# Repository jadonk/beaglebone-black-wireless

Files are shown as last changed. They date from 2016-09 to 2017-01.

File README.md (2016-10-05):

# BeagleBoard.org BeagleBone Black Wireless
WiFi/BT version of BeagleBone Black done in EAGLE

# Terms
These design materials are *NOT SUPPORTED* and *DO NOT* constitute a reference design. Only “community” support is allowed via resources at [BeagleBoard.org/discuss](https://beagleboard.org/discuss).

THERE IS NO WARRANTY FOR THE DESIGN MATERIALS, TO THE EXTENT PERMITTED BY APPLICABLE LAW. EXCEPT WHEN OTHERWISE STATED IN WRITING THE COPYRIGHT HOLDERS AND/OR OTHER PARTIES PROVIDE THE DESIGN MATERIALS “AS IS” WITHOUT WARRANTY OF ANY KIND, EITHER EXPRESSED OR IMPLIED, INCLUDING, BUT NOT LIMITED TO, THE IMPLIED WARRANTIES OF MERCHANTABILITY AND FITNESS FOR A PARTICULAR PURPOSE. THE ENTIRE RISK AS TO THE QUALITY AND PERFORMANCE OF THE DESIGN MATERIALS IS WITH YOU. SHOULD THE DESIGN MATERIALS PROVE DEFECTIVE, YOU ASSUME THE COST OF ALL NECESSARY SERVICING, REPAIR OR CORRECTION.

We mean it, these design materials may be totally unsuitable for any purposes.

Do not use the BeagleBoard.org logo on your products without a [logo license](https://beagleboard.org/logo), but feel free to reference BeagleBoard.org.

See the [LICENSE](https://github.com/beagleboard/beaglebone-black-wireless/blob/master/LICENSE) file regarding the copyright of these materials.

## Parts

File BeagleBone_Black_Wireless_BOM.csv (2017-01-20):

Parts | Qty | Manufacturer | MPN | Description
BAG | 1 |  | 50-18 | 3x5 Open Top Anti-Static Bag
 |  | Desco | 13605
BOX | 1 |  |  | BeagleBone Black Wireless Box
CABLE | 1 |  | 13564 | USB 2.0 A to Micro B Cable 3ft
 |  | Molex | 68784-0002
PCB | 1 |  | BeagleBone Black Wireless A5b | BeagleBone Black Wireless A5b
QSG | 1 |  |  | BeagleBone Black Wireless Quick Start
ANT1-1, ANT2-1 | 2 | Anaren Microwave | 66089-2430 | 2.4GHz Whip, Straight RF Antenna 3dBi Connector, U.FL Connector Mount
ANT1, ANT2 | 2 | Hirose | U.FL-R-SMT-1(10) | CONN UMC JACK STR 50 OHM SMD
BT, PWR, USR0. USR1, USR2, USR3, WL | 7 | Lite-On | LTST-C191TBKT | LED BLUE CLEAR THIN 0603 SMD
C1, C19, C20, C61 | 4 | Samsung | CL10A106MQ8NNNC | CAP. 10uF 6.3V (0603)
C16, C55, C56 | 3 | Samsung | CL10A225KQ8NNNC | CAP. 2.2uF 6.3V (0603)
C2, C13, C15, C17, C18, C21, C22, C24, C25, C43. C44, C45, C47, C48, C49, C50, C51, C52, C53, C58, C59, C63, C69 | 23 | Murata | GRM155R60J104KA01D | CAP CER 0.1UF 6.3V 10% X5R 0402
C27, C28, C29, C30, C31, C32, C33, C34, C35, C36, C37, C39, C40, C41, C42 | 16 | Yageo | CC0402JRNPO9BN470 | CAP CER 47PF 50V 5% NPO 0402
C3, C4, C5, C6 | 4 | NIC Components | NMC0402NPO180J50TRPF | CAP CER 18PF 50V C0G 5% 0402
C46, C60 | 2 | Samsung | CL05C100JB5NNNC | CAP. 10pF 50V (0402)
C62 | 1 | AVX | TAJD227M010RNJ | CAP. 220uF TANT. 10V (7343)
 |  | AVX | TAJD227K010RNJ
C7 | 1 | Samsung | CL21A475KOFNNNE | CAP. 4.7uF (0805)
C8, C10, C64 | 3 | Murata | GRM155R60J105KE19D | CAP CER 1UF 6.3V 10% X5R 0402
C9, C12, C14, C54, C57 | 5 | Samsung | CL21B225KOFNNNE | CAP. 2.2uF 16V (0805)
D1 | 1 | NXP Semiconductors | RB751V40,115 | DIODE SCHOTTKY 40V 120MA SOD-323
D3. D4 | 2 | Diodes Inc. | B130L-13-F | B130L-13 (SMA)
D8 | 1 | ON Semiconductor | BAT54CLT1G | BAT54C (SOT-23)
F1 | 1 | Littelfuse | 1206L050YR | 1206L050YR (1206)
FB1 | 1 | Murata | BLM21AG221SN1D | FB 220 OHM 0805
FB2 | 1 | Murata | BLM18BD252SN1D | FB 2.5K (0603)
FB3 | 1 | Laird | LI0805H151R-10 | Ferrite Bead 150 Ohm 800mA
FB4, R17 | 2 | CTS Components | 73L3R10J | RES .10 OHM 1/8W 5% 0805
FB5, FB6, FB7 | 3 | Murata | BLM15AG102SN1D | FERRITE BEAD 1 KOHM 0402 1LN
IC1 | 1 | Octavo Systems | OSD3358-512M-BAS | OSD3358-512M-BAS-XB for Beagleboard.org
IC10, IC11 | 2 | Texas Instruments | TXS0108ERGYR | IC XLATR VOLT-LVL 8B BDIR 20QFN
IC12 | 1 | Texas Instruments | TPS2051BDGNR | IC 1.5A PWR DIST SWITCH 8-SOIC
IC13 | 1 | Texas Instruments | SN74AUC1G74DCTR | IC D-TYPE POS TRG SNGL SM8
IC14, IC15 | 2 | Texas Instruments | TPD4S012DRYR | IC 4CH ESD SOLUTION W/CLAMP 6SON
IC17 | 1 | Texas Instruments | SN74LVC2G241DCUR | IC BUFF/DVR TRI-ST DL 8VSSOP
IC18 | 1 | Texas Instruments | TL1963ADCQR | IC REG LDO ADJ 1.5A SOT223-6
IC19 | 1 | Diodes Inc. | AP2112K-1.8TRG1 | AP2112K-1.8TRG1
IC2 | 1 | Texas Instruments | SN74LVC1G07DCKR | IC BUFF/DVR NON-INVERT SC705
IC22 | 1 | Kingston | EMMC04G-S100-B08U | IC MEMORY, 4GB eMMC
IC3 | 1 | Texas Instruments | SN74LVC1G06DCKR | IC INVERTER SINGLE 1INPUT SC705
IC4 | 1 | Microchip | 24LC32AT-I/OT | IC EEPROM 32KBIT 400KHZ SOT23-5
IC5 | 1 | Texas Instruments | TLVH431IDBZR | IC VREF SHUNT ADJ SOT23-3
IC7, IC8 | 2 | NXP Semiconductors | IP4283CZ10-TBR | TVS DIODE 5.5VWM 9.5VC 10DFN
IC9 | 1 | NXP Semiconductors | TDA19988BHN/C1,557 | IC HDMI INTERFACE HVQFN64
MOD1 | 1 | Texas Instruments | WL1835MODGBMOCR | MODULE WIFI WILINK
OSC1 | 1 | Abracon | ASDMB-24.576MHZ-LC-T | Oscillator, 24.576MHZ, 3.3V
OSC2 | 1 | NDK | NZ2520SB-32.768KHZ-NSA3534C | OSC XO 32.768KHZ CMOS SMD
P8, P9 | 2 | Major League Electronics | SSHS-123-D-02-GT-LF | NN HEADER FMAL 46PS.1" DL GOLD"
POWER, RESET, S2 | 3 | C&K Components | KMR231GLFS | Mini Switch
 |  | Zhejiang Jianfu Electronics Co., LTD. | TVAF02-NB-R
Q2 | 1 |  | 6K30032768K0702070401 | 3.2x1.5 2pads 32.768kHz 7pF 20ppm
 |  | Interquip | 9CAA32768072TF70QT
Q4 | 1 | TXC | 7A-24.000MAAJ-T | CRYSTAL 24.000 MHZ 18PF SMD
R1, R2, R3, R4, R5, R6, R7, R12, R13, R16, R18, R19, R20, R23, R24, R25, R28, R30, R31, R32, R33, R40, R46, R98, R99, R101, R102, R103, R105, R119, R121 | 31 | Samsung | RC1005F103CS | RES. 10K 1% (0402)
R10, R11 | 2 | Samsung | RC1005J154CS | RES. 150K 5% (0402)
R120 | 1 | Yageo | RC0402FR-0727KL | RES 27K OHM 1/16W 1% 0402 SMD
R14, R26, R27, R29, R35, R36, R37, R38, R39, R54, R114, R122 | 12 | Yageo | RC0402JR-070RL | Resistor Zero ohm Jumper 0402
R21, R22, R43, R52, R53, R55 | 6 | NIC Components | NRC04F4751TRF | RES 4.75K OHM 1/16W 1% 0402 SMD
R34 | 1 | NIC Components | NRC04J220TRF | Resistor 22ohm 1/16W 1% 0402
R41, R42, R106, R115, R118 | 5 | Yageo | RC0402FR-071K5L | RES 1.50K OHM 1/16W 1% 0402 SMD
 |  |  | RC0402FR-071ML
R44 | 1 | Samsung | RC1005F4990CS | RES. 499 OHM 1% (0402)
R47 | 1 | Samsung | RC1005F4022CS | RES. 40.2K 1% (0402)
R57, R58, R61, R63, R65, R67, R69, R71, R73, R75, R76, R78, R80, R82, R85, R87, R123 | 17 | Yageo | RC0402FR-07100KL | Resistor 100Kohm 1/16W 1% 0402
R60, R62, R64, R66, R68, R70, R72, R110, R140, R141, R142, R143 | 12 | Yageo | RC0402JR-0733RL | RES 33 OHM 1/16W 5% 0402 SMD
R8, R95 | 2 | Yageo | RC0402FR-071ML | Resistor 1Mohm 1/16W 1% 0402
R86, R126, R127, R128, R129, R130, R131, R134, R135, R136 | 10 | Samsung | RC1608J330CS | RES. 33 OHM 5% (0603)
R88 | 1 | Samsung | RC1005F101CS | RES. 100 OHM 1% (0402)
R89, R90, R92, R96, R100, R104, R124, R125 | 8 | Samsung | RC1005J102CS | RES. 1K 5% (0402)
R93 | 1 | Samsung | RC1005F7151CS | RES. 7.15K 1% (0402)
R94 | 1 | Samsung | RC1005F4121CS | RES 4.12K OHM 1/16W 1% 0402 SMD
T1 | 1 | ON Semiconductor | MMBT2907ALT1G | TRANS PNP 60V 0.6A SOT23
T3, T4 | 2 | Diodes Inc. | BSS138W-7-F | MOSFET N-CH 50V 200MA SC70-3
X1 | 1 | FCI | 68000-406HLF | CONN HEADER 6POS, VERTICAL, .100 STR TIN
X12 | 1 | CUI | PJ-102A | Power Jack
X2 | 1 | ALPS | SCHA5B0200 | Connector SD/MMC
X3 | 1 | TE Connectivity / AMP | 787616-1-P | Single Row USB Right Angle
 |  |  | LY-USB-004-001-A1
X4 | 1 | FCI | 10118192-0001LF | USB - micro B USB 2.0 Receptacle Connector 5 Position Surface Mount, Right Angle, Horizontal
X5 | 1 | FCI | 10118241-001RLF | HDMI / Displayport / DVI Connectors MICRO HDMI RCPT SMT DIP+ SMT LEG TYPE D

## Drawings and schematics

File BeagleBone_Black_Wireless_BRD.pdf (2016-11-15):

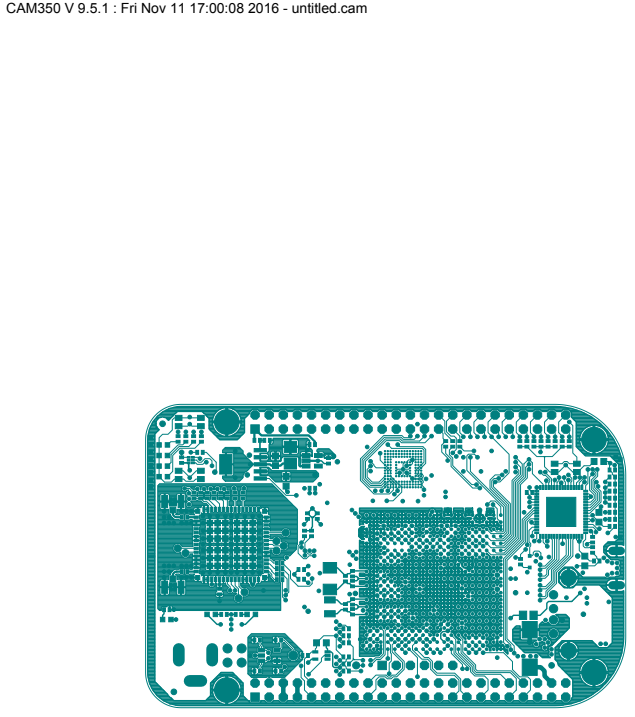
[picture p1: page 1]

CAM350 V 9.5.1 : Fri Nov 11 17:00:08 2016 - untitled.cam

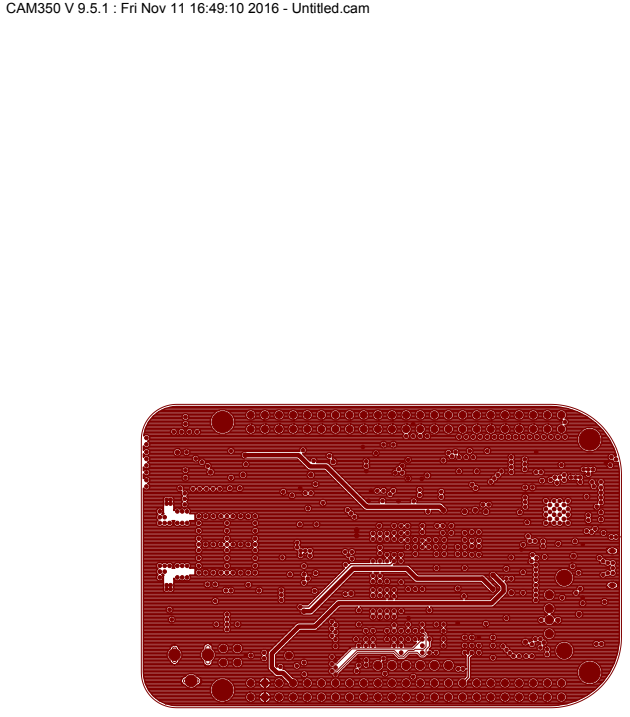
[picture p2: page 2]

CAM350 V 9.5.1 : Fri Nov 11 16:49:10 2016 - Untitled.cam

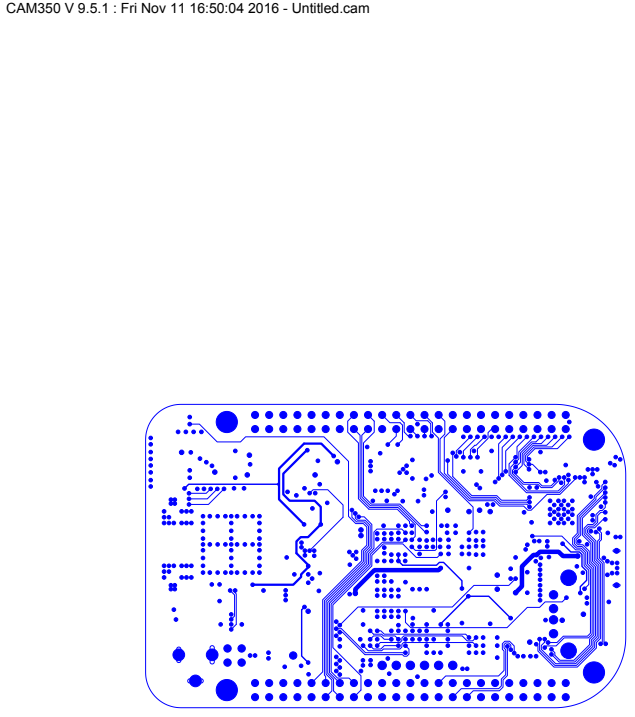
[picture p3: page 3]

CAM350 V 9.5.1 : Fri Nov 11 16:50:04 2016 - Untitled.cam

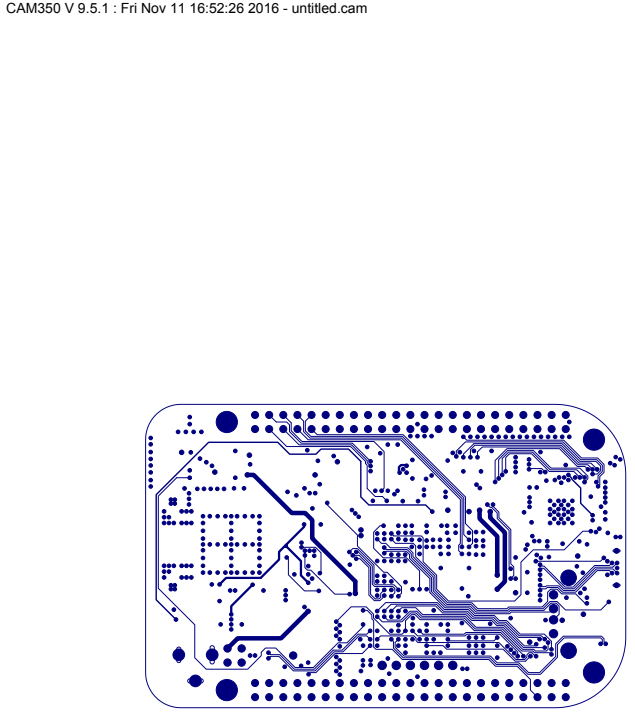
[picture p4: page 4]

CAM350 V 9.5.1 : Fri Nov 11 16:52:26 2016 - untitled.cam

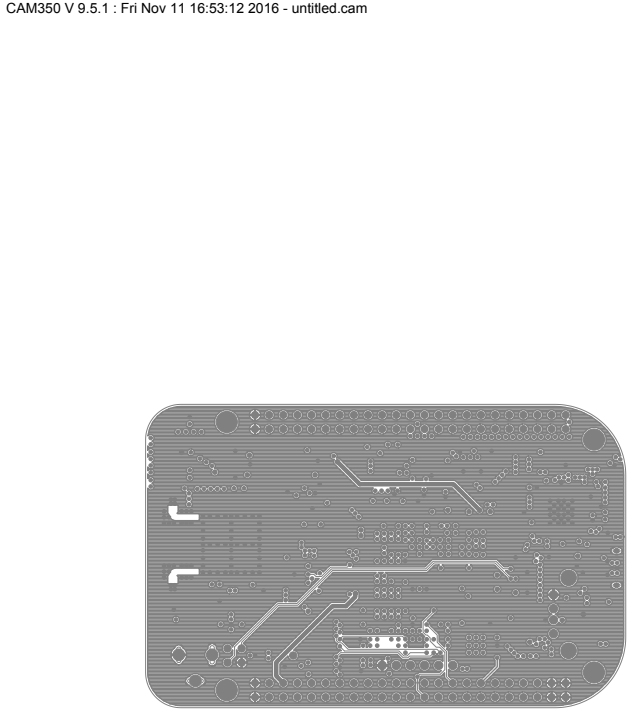
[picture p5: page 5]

CAM350 V 9.5.1 : Fri Nov 11 16:53:12 2016 - untitled.cam

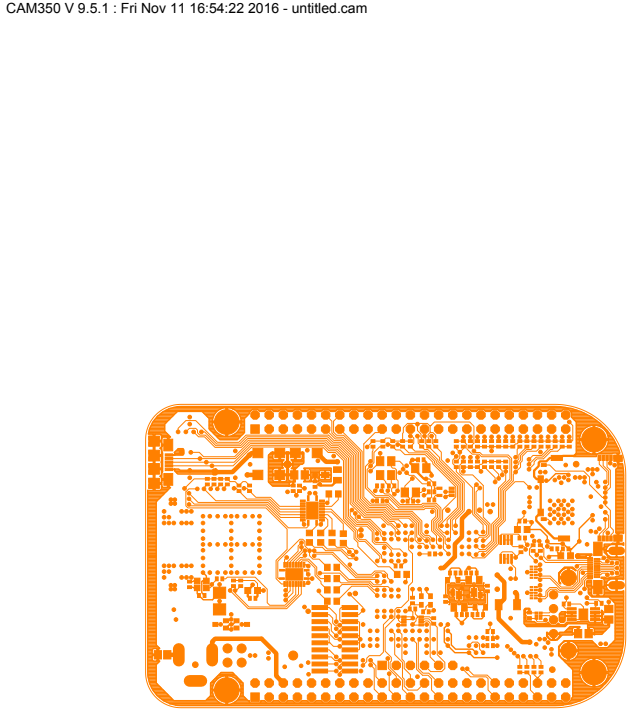
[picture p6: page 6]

CAM350 V 9.5.1 : Fri Nov 11 16:54:22 2016 - untitled.cam

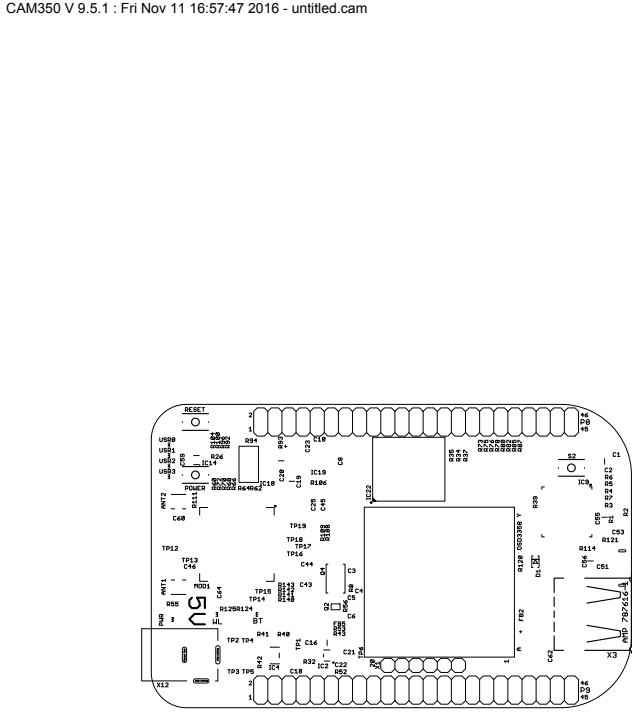
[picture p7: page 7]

CAM350 V 9.5.1 : Fri Nov 11 16:57:47 2016 - untitled.cam

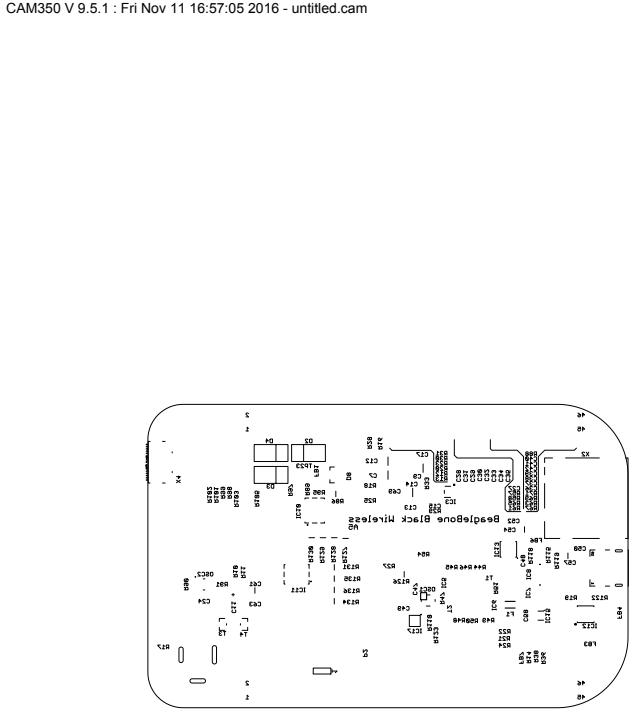
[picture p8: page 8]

CAM350 V 9.5.1 : Fri Nov 11 16:57:05 2016 - untitled.cam

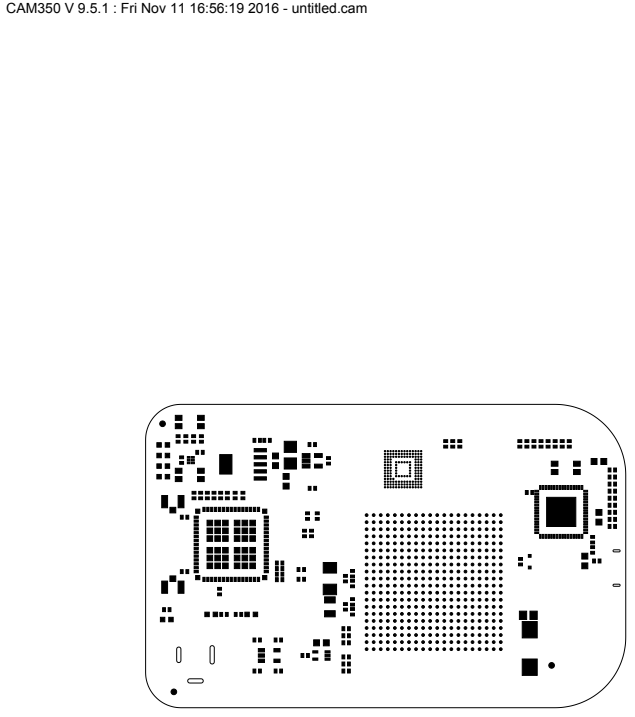
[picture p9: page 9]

CAM350 V 9.5.1 : Fri Nov 11 16:56:19 2016 - untitled.cam

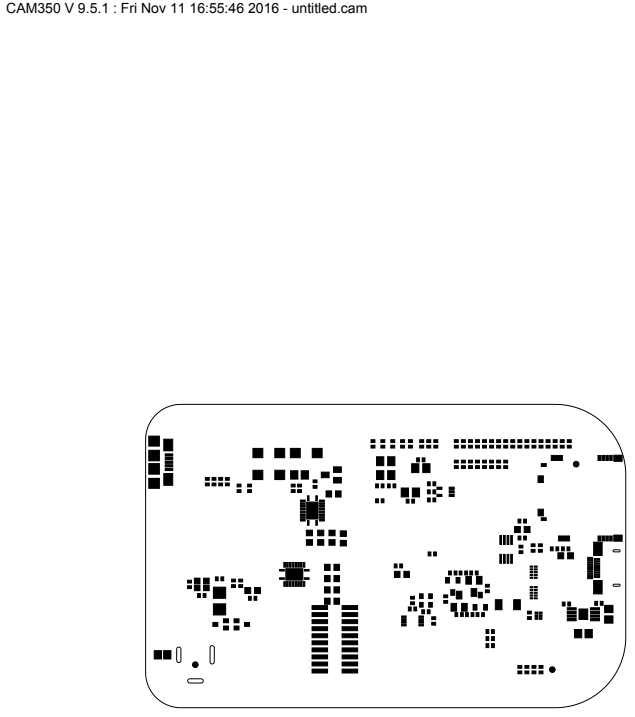
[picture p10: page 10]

CAM350 V 9.5.1 : Fri Nov 11 16:55:46 2016 - untitled.cam

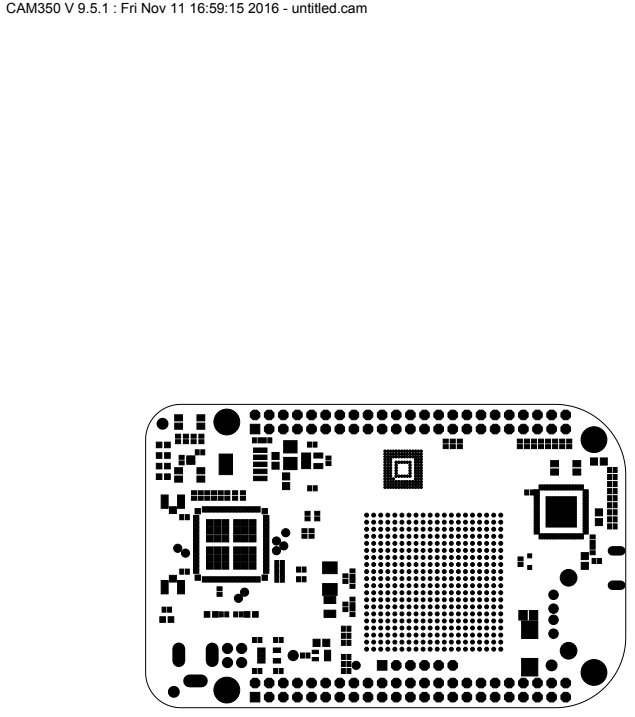
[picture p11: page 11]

CAM350 V 9.5.1 : Fri Nov 11 16:59:15 2016 - untitled.cam

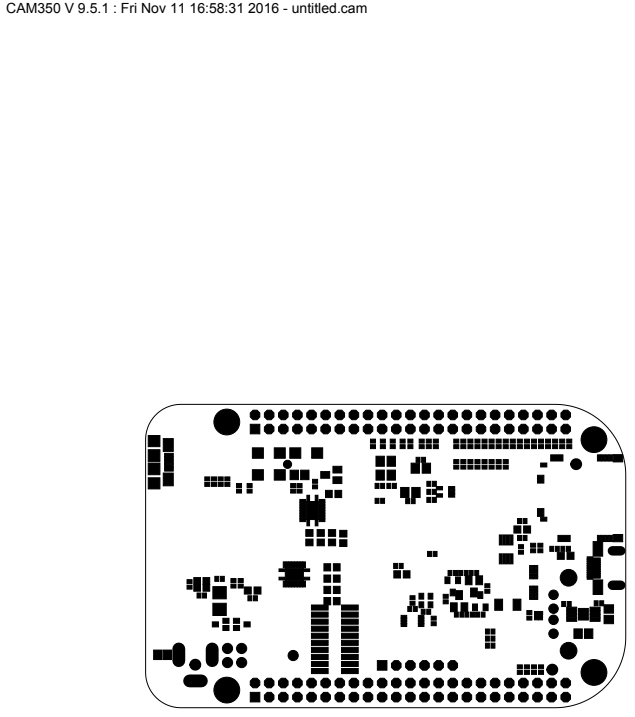
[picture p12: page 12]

CAM350 V 9.5.1 : Fri Nov 11 16:58:31 2016 - untitled.cam


CAM350 V 9.5.1 : Fri Nov 11 16:55:00 2016 - untitled.cam


CAM350 V 9.5.1 : Fri Nov 11 17:02:55 2016 - untitled.cam


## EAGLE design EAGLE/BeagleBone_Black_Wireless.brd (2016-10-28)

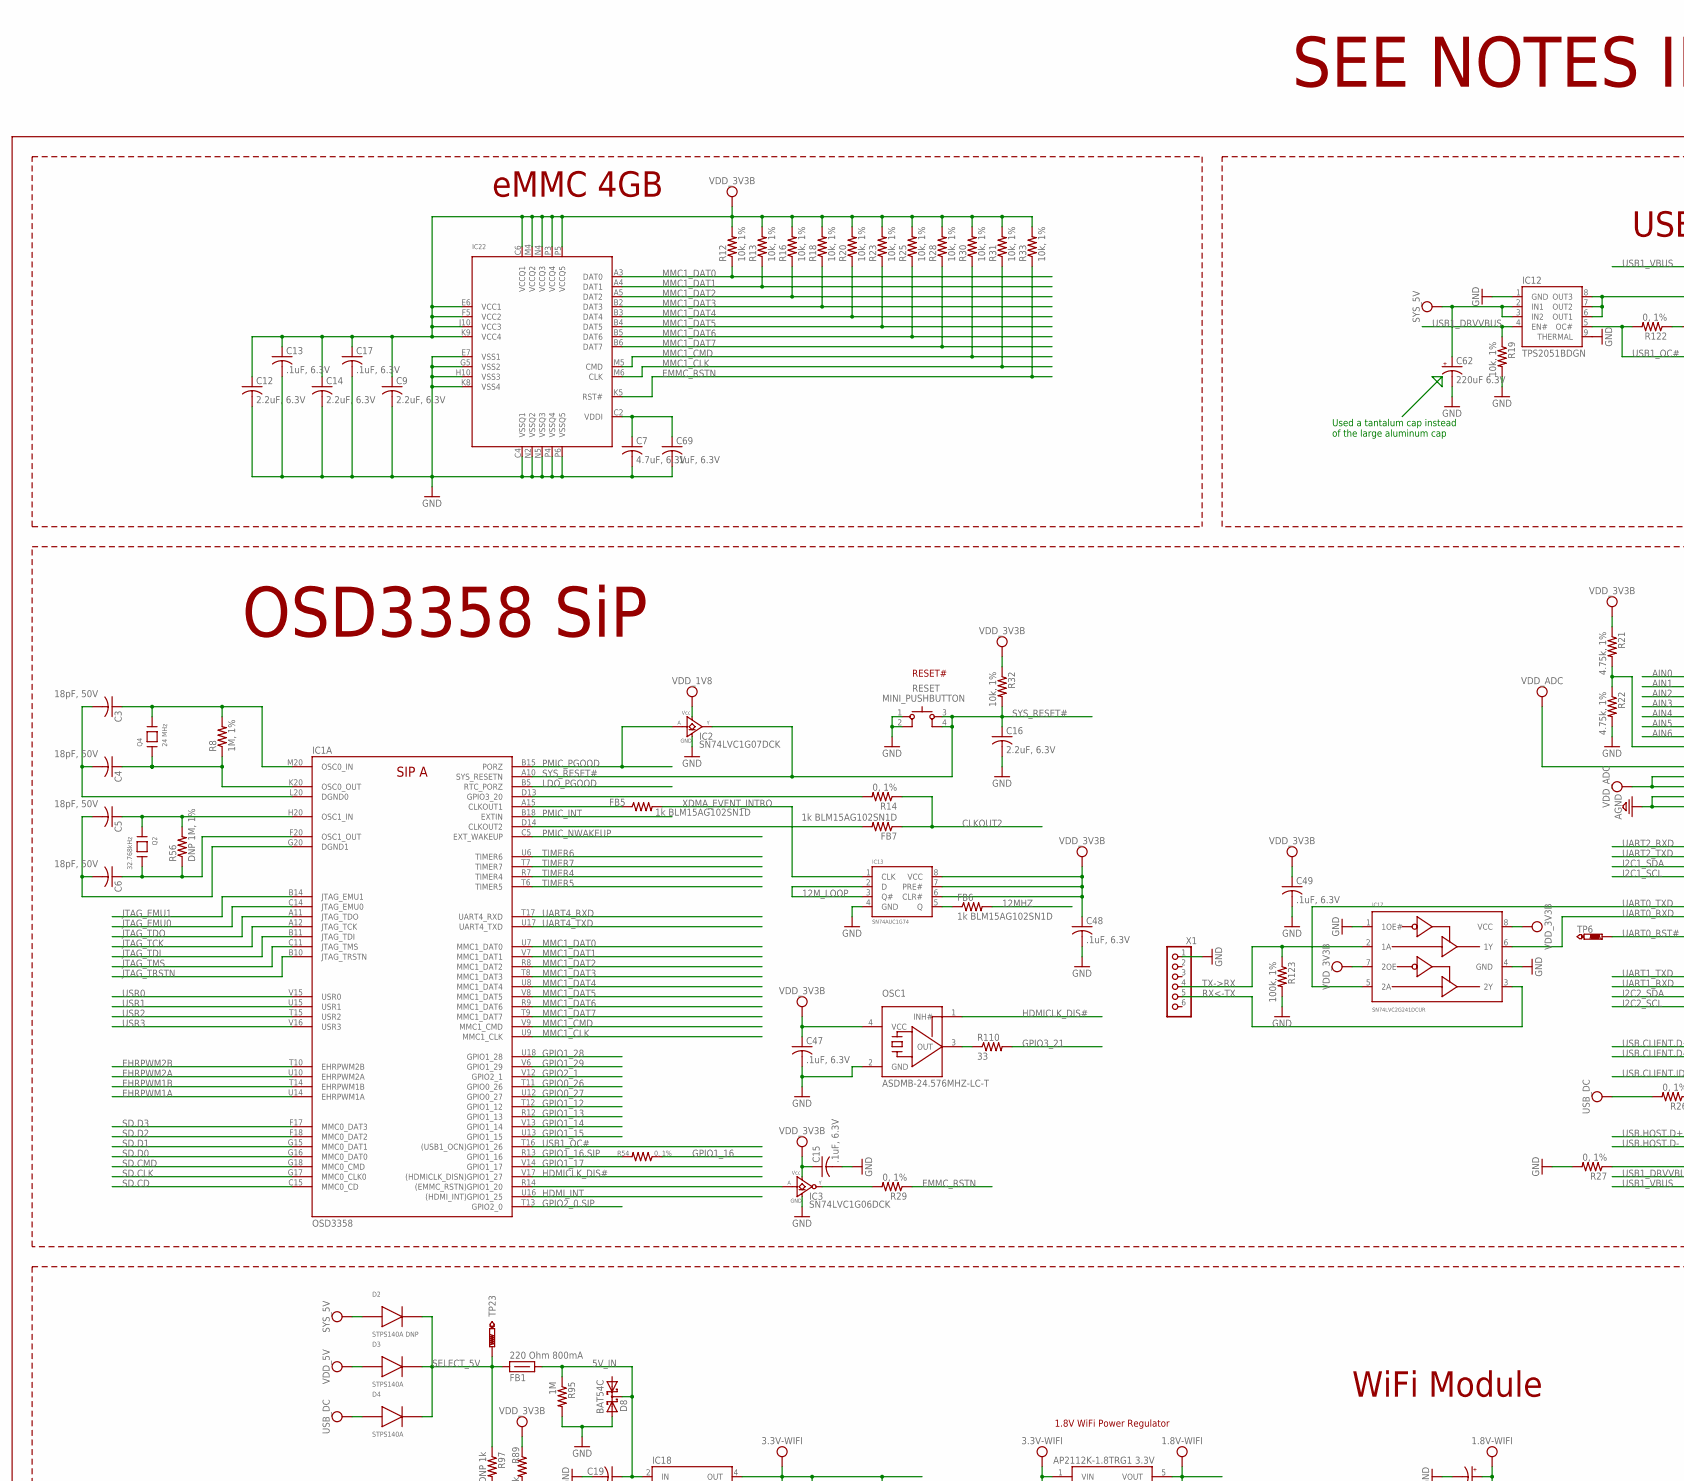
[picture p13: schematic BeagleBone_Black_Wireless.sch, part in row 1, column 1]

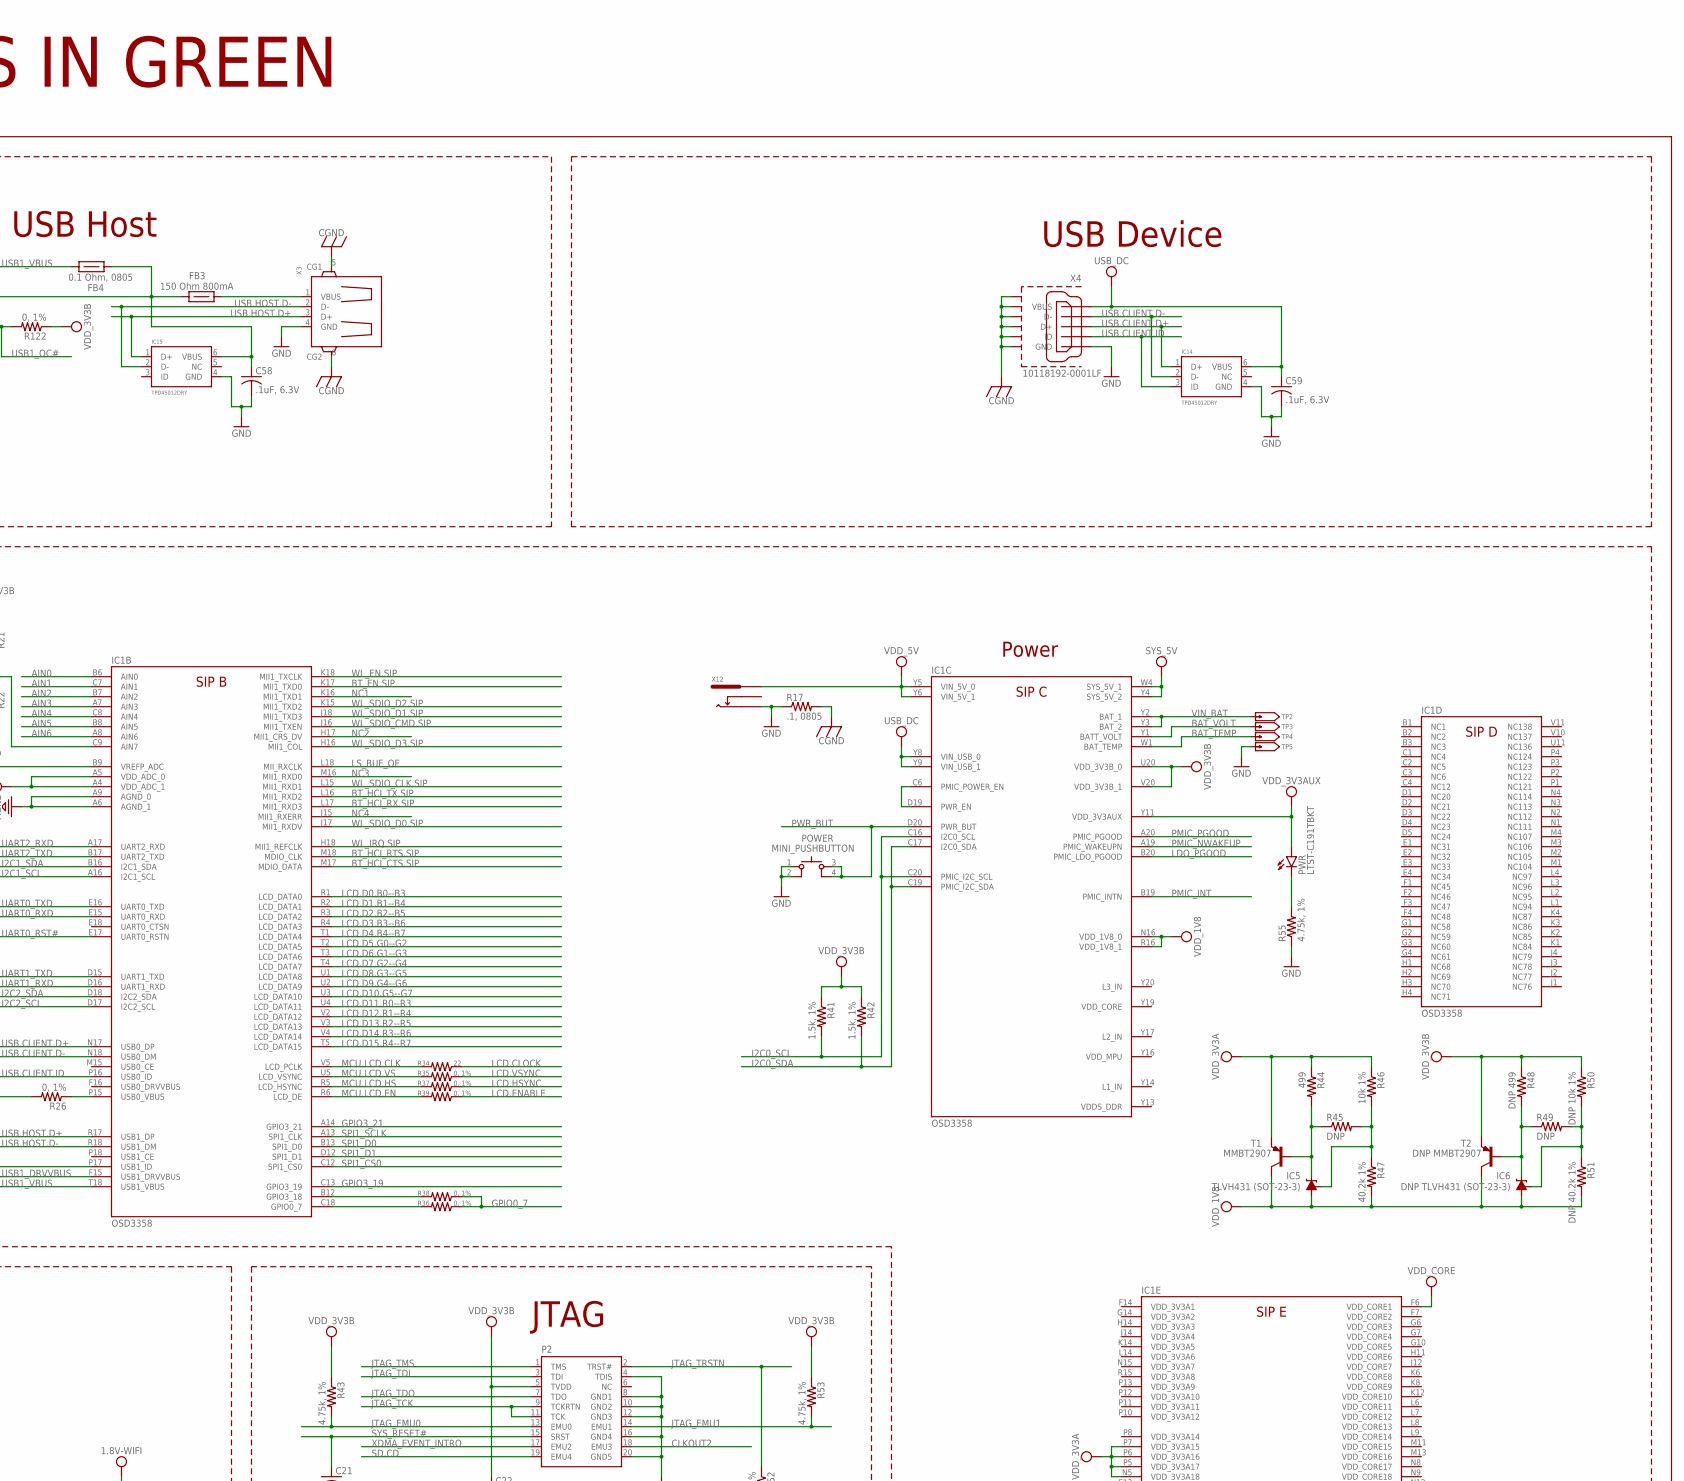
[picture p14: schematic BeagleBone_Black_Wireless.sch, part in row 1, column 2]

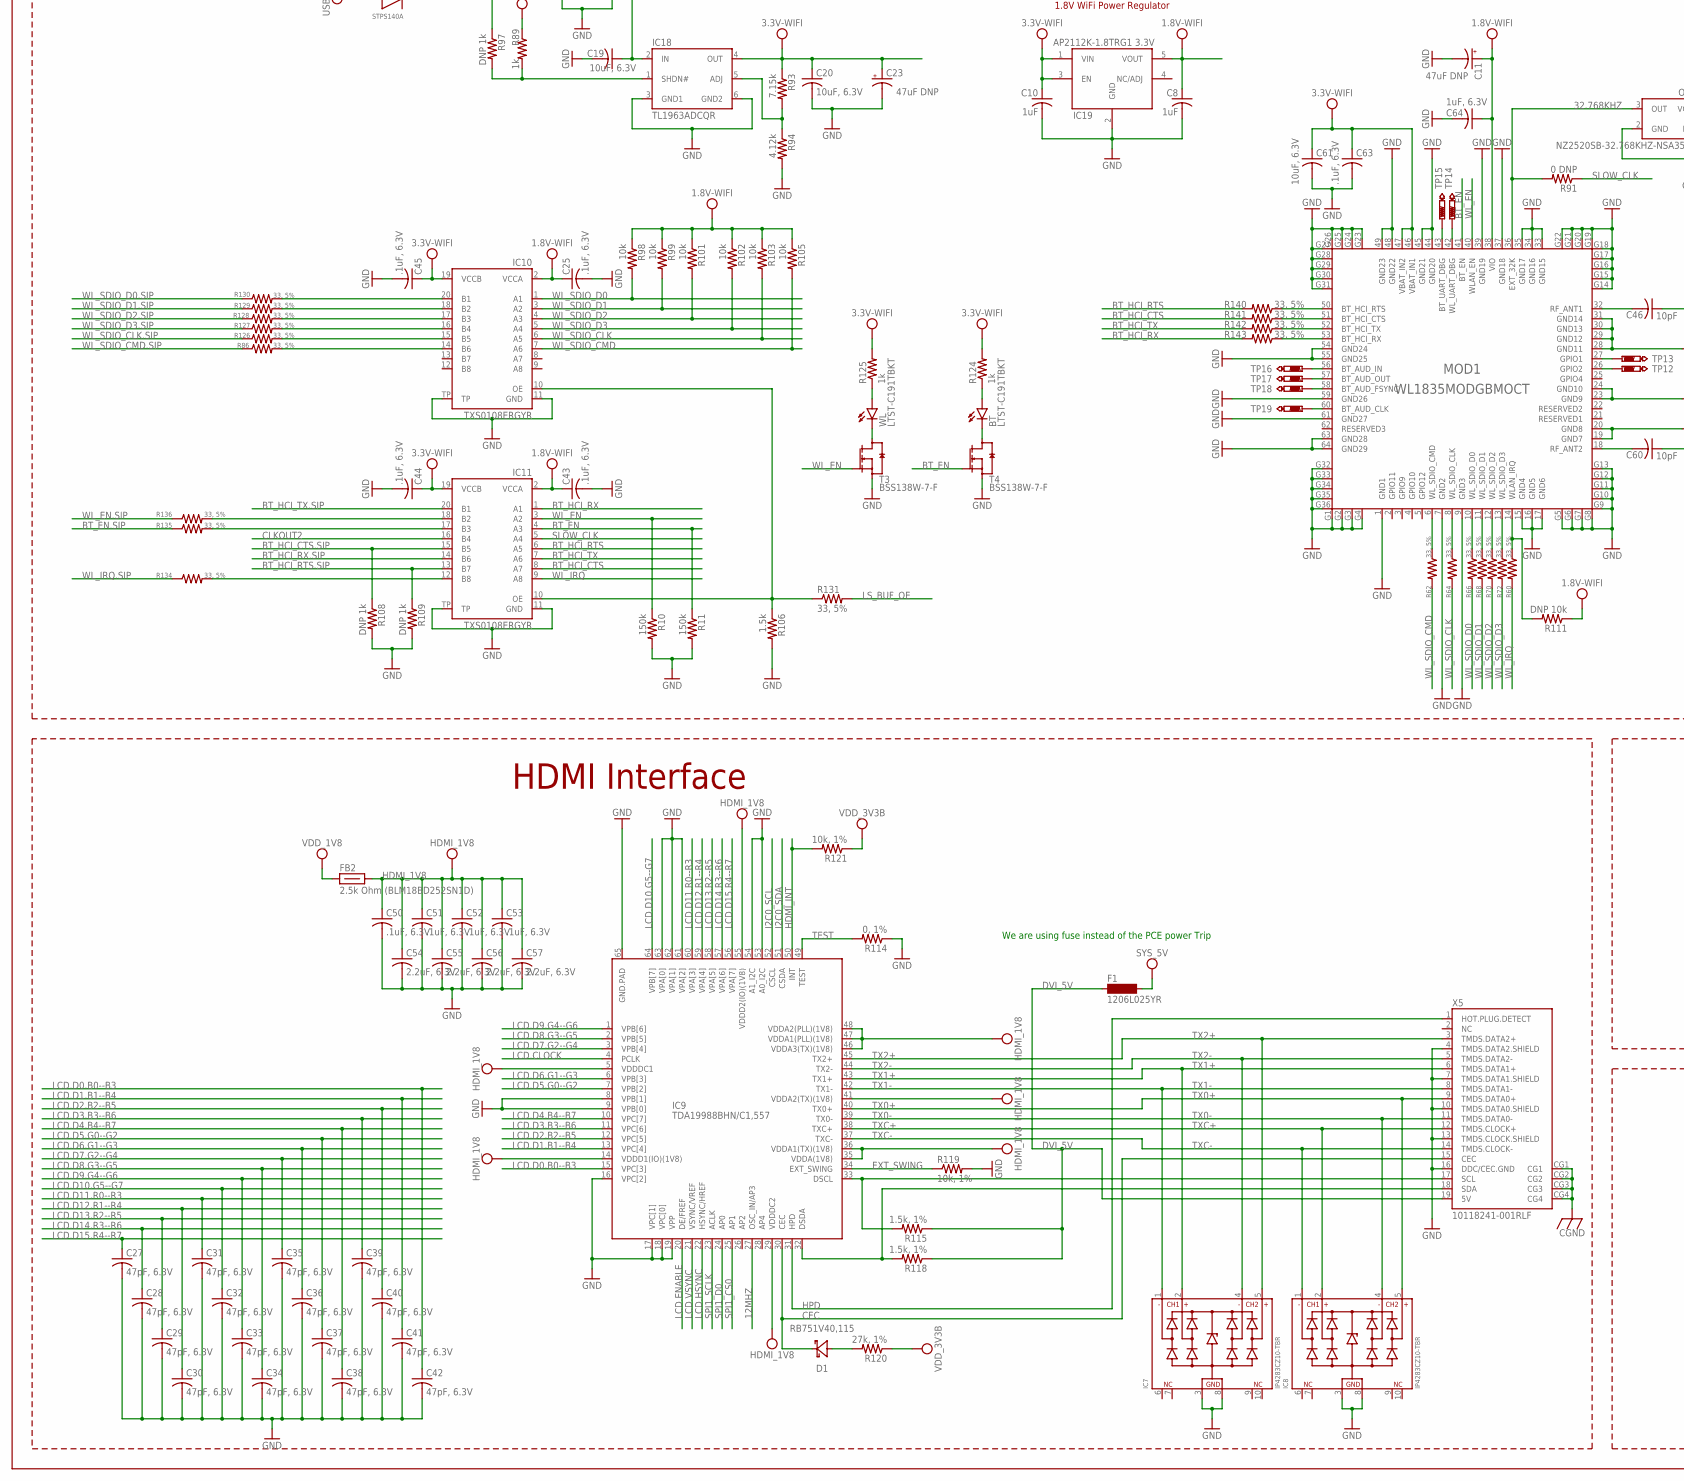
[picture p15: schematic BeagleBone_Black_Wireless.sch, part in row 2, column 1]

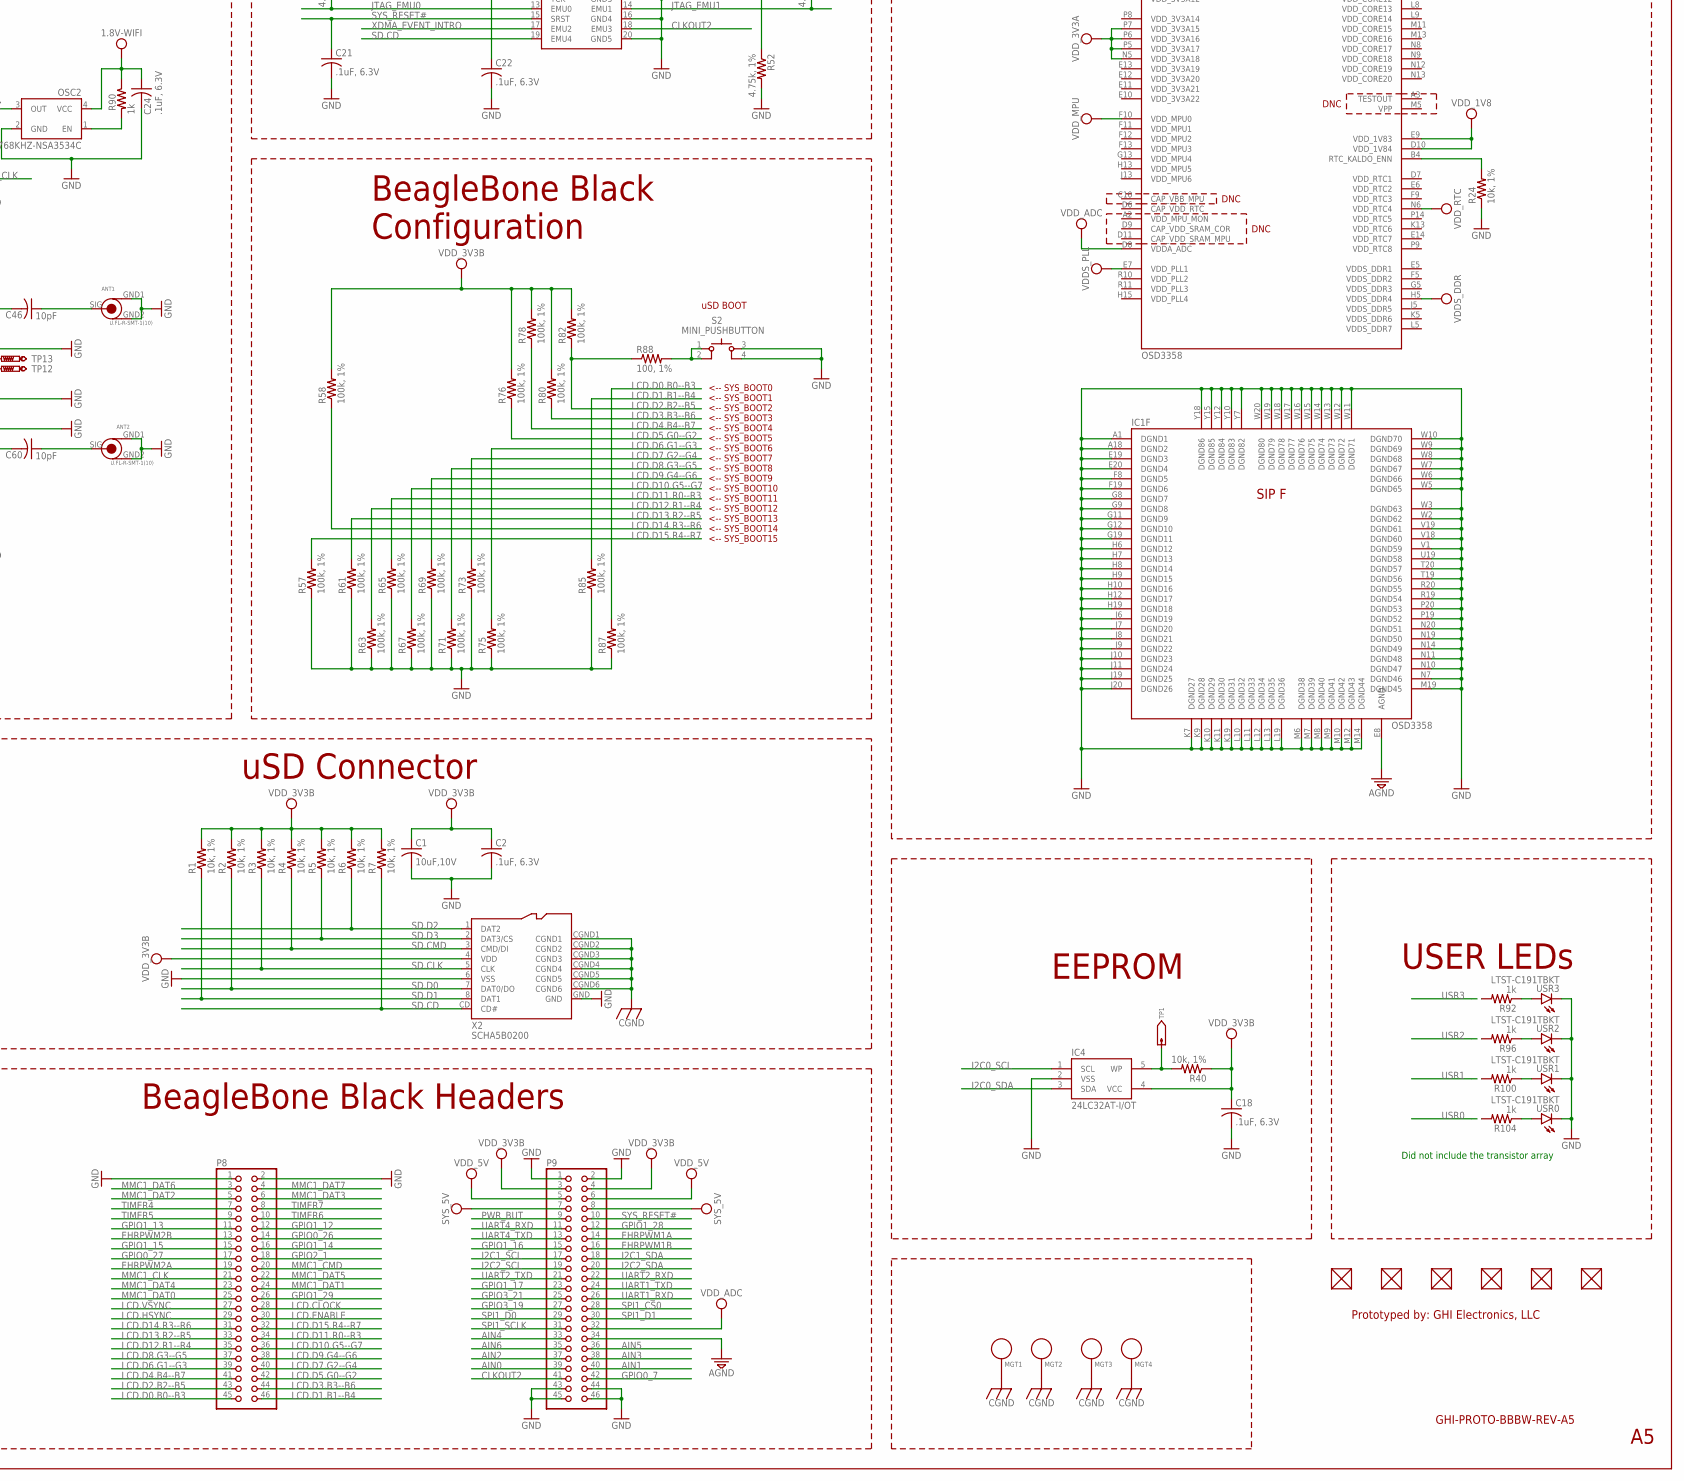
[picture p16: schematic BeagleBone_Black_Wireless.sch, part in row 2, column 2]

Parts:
ANT1, ANT2: U.FL-R-SMT-1(10); U.FL-R-SMT-1
BT: LTST-C191TBKT; 0603-LED
C1: 10uF,10V; C0603K
C2, C13, C15, C17, C18, C21, C22, C24, C25, C43, C44, C45, C47, C48, C49, C50, C51, C52, C53, C58, C59, C63, C69: .1uF, 6.3V; C0402K
C3, C4, C5, C6: 18pF, 50V; C0402K
C7: 4.7uF, 6.3V; C0805K
C8, C10: 1uF; C0402K
C9, C12, C14: 2.2uF, 6.3V; C0805K
C11, C23: 47uF DNP; CT3528
C16, C54, C55, C56, C57: 2.2uF, 6.3V; C0603K
C19, C20, C61: 10uF, 6.3V; C0603K
C27, C28, C29, C30, C31, C32, C33, C34, C35, C36, C37, C38, C39, C40, C41, C42: 47pF, 6.3V; C0402K
C46, C60: 10pF; C0402K
C62: 220uF 6.3V; D/7343-31W
C64: 1uF, 6.3V; C0402K
D1: RB751V40,115; SOD323(NXP)REFLOW
D2: STPS140A DNP; DIODE_SMA
D3, D4: STPS140A; DIODE_SMA
D8: BAT54C; SOT23
F1: 1206L025YR; SM-1206
FB1: 220 Ohm 800mA; 0805-RESISTOR
FB2: 2.5k Ohm (BLM18BD252SN1D); 0805-RESISTOR
FB3: 150 Ohm 800mA; 0805-RESISTOR
FB4: 0.1 Ohm, 0805; 0805-RESISTOR
FB5, FB6, FB7: 1k BLM15AG102SN1D; R0402
FUD1, FUD2, FUD3, FUD4, FUD5, FUD6: FIDUCIAL; FIDUCIAL_40MIL
IC1: OSD3358
IC2: SN74LVC1G07DCK; SC70(TI-DCK)
IC3: SN74LVC1G06DCK; SC70(TI-DCK)
IC4: 24LC32AT-I/OT; SOT23-5(MICROCHIP)
IC5: TLVH431 (SOT-23-3); DBZ_R-PDSO-G3
IC6: DNP TLVH431 (SOT-23-3); DBZ_R-PDSO-G3
IC7, IC8: IP4283CZ10-TBR; SOT1176-1(NXP)
IC9: TDA19988BHN/C1,557; SOT804-4(NXP)
IC10, IC11: TXS0108ERGYR; R-PVQFN-N20(TI)
IC12: TPS2051BDGN; MSOP-POWER.PAD-8(TI)
IC13: SN74AUC1G74; SM8-8(TI)
IC14, IC15: TPD4S012DRY; SON-6(TI)-DRY
IC17: SN74LVC2G241DCUR; VSSOP8(TI)
IC18: TL1963ADCQR; SOT-223(DCQ_R-PDSO-G6_TI)
IC19: AP2112K-1.8TRG1 3.3V; SOT23-5
IC22: EMMC04G-S100-B08U; MICRON_EMMC_153
MGT1, MGT2, MGT3, MGT4: MOUNTING_HOLE
MOD1: WL1835MODGBMOCT; MOC-100(TI)
OSC1: ASDMB-24.576MHZ-LC-T; OSCILLATOR-2.5X2.0-BBB
OSC2: NZ2520SB-32.768KHZ-NSA3534C; NZ2520S
P2: JTAG
P8, P9: HEADER-2X23-(INCH)-0.1-TH; TH-2X23
POWER: MINI_PUSHBUTTON
PWR: LTST-C191TBKT; 0603-LED
Q2: 32.768kHz; CRYSTAL_3.2X1.5
Q4: 24 MHz; CRYSTAL_5X3.2MM
R1, R2, R3, R4, R5, R6, R7, R12, R13, R16, R18, R19, R20, R23, R24, R25, R28, R30, R31, R32, R33, R40, R119, R121: 10k, 1%; R0402
R8: 1M, 1%; R0402
R10, R11: 150k; R0402
R14, R26, R27, R29, R35, R36, R37, R38, R39, R54, R114, R122: 0, 1%; R0402
R17: .1, 0805; R0805
R21, R22, R43, R52, R53, R55: 4.75k, 1%; R0402
R34: 22; R0402
R41, R42, R115, R118: 1.5k, 1%; R0402
R44: 499; R0402
R45, R49: DNP; R0402
R46: 10k 1%; R0402
R47: 40.2k 1%; R0402
R48: DNP 499; R0402
R50: DNP 10k 1%; R0402
R51: DNP 40.2k 1%; R0402
R56: DNP 1M, 1%; R0402
R57, R58, R61, R63, R65, R67, R69, R71, R73, R75, R76, R78, R80, R82, R85, R87, R123: 100k, 1%; R0402
R60, R62, R64, R66, R68, R70, R72, R140, R141, R142, R143: 33, 5%; R0402
R86, R126, R127, R128, R129, R130, R131, R134, R135, R136: 33, 5%; R0603
R88: 100, 1%; R0402
R89, R90, R92, R96, R100, R104, R124, R125: 1k; R0402
R91: 0 DNP; R0402
R93: 7.15k; R0402
R94: 4.12k; R0402
R95: 1M; R0402
R97, R108, R109: DNP 1k; R0402
R98, R99, R101, R102, R103, R105: 10k; R0402
R106: 1.5k; R0402
R110: 33; R0402
R111: DNP 10k; R0402
R120: 27k, 1%; R0402
RESET: MINI_PUSHBUTTON
S2: MINI_PUSHBUTTON
T1: MMBT2907; SOT23-BEC
T2: DNP MMBT2907; SOT23-BEC
T3, T4: BSS138W-7-F; SOT-323(DIODES)
TP1, TP2, TP3, TP4, TP5: TESTPAD/W_HOLE_1X1
TP6, TP12, TP13, TP14, TP15, TP16, TP17, TP18, TP19, TP23: PTR1B1,27; B1,27
USR0, USR1, USR2, USR3: LTST-C191TBKT; 0603-LED
WL: LTST-C191TBKT; 0603-LED
X1: 1X6-(INCH)-0.1-TH; TH-1X6
X2: SCHA5B0200
X3: USB_HOST_W/CHASSIS_GND; USB_HOST_HORIZONTAL_W/CHASSIS_GND
X4: 10118192-0001LF; 10118192-0001LF(MICRO-USB-B-AMPHENOL-FCI)
X5: 10118241-001RLF; HDMI-TYPE-D-10118241
X12: PJ-102B_POWER_CON

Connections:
1.8V-WIFI: C8.1, C11.+, C24.1, C25.1, C43.1, C64.1, IC10.2 (VCCA), IC11.2 (VCCA), IC19.5 (VOUT), MOD1.38 (VIO), OSC2.4 (VCC), R90.1, R98.1, R99.1, R101.1, R102.1, R103.1, R105.1, R111.1
3.3V-WIFI: C10.1, C20.1, C23.+, C44.1, C45.1, C61.1, C63.1, IC10.19 (VCCB), IC11.19 (VCCB), IC18.4 (OUT), IC19.1 (VIN), IC19.3 (EN), MOD1.46 (VBAT_IN1), MOD1.47 (VBAT_IN2), R93.1, R124.2, R125.2
5V_IN: C19.1, D8.3 (CC), FB1.2, IC18.2 (IN), R95.1
12MHZ: FB6.2, IC9.27 (OSC_IN/AP3)
12M_LOOP: IC13.2 (D), IC13.3 (Q#)
32.768KHZ: MOD1.36 (EXT_32K), OSC2.3 (OUT), R91.2
AGND: IC1.A6 (AGND_1), IC1.A9 (AGND_0), IC1.E8 (AGND), P9.34
AIN0: IC1.B6 (AIN0), P9.39
AIN1: IC1.C7 (AIN1), P9.40
AIN2: IC1.B7 (AIN2), P9.37
AIN3: IC1.A7 (AIN3), P9.38
AIN4: IC1.C8 (AIN4), P9.33
AIN5: IC1.B8 (AIN5), P9.36
AIN6: IC1.A8 (AIN6), P9.35
AIN7: IC1.C9 (AIN7), R21.2, R22.1
ALT.BT.EN: IC11.17 (B3), R135.2
ALT.BUFF.OE: IC10.10 (OE), IC11.10 (OE), R106.1, R131.1
ALT.WL.CLK: IC10.15 (B5), R126.2
ALT.WL.CMD: IC10.14 (B6), R86.2
ALT.WL.D0: IC10.20 (B1), R130.2
ALT.WL.D1: IC10.18 (B2), R129.2
ALT.WL.D2: IC10.17 (B3), R128.2
ALT.WL.D3: IC10.16 (B4), R127.2
ALT.WL.EN: IC11.18 (B2), R136.2
ALT.WL.IRQ: IC11.12 (B8), R134.2
BAT_TEMP: IC1.W1 (BAT_TEMP), TP4.P$1
BAT_VOLT: IC1.Y1 (BATT_VOLT), TP3.P$1
BT_EN: IC11.4 (A3), MOD1.41 (BT_EN), R11.1, T4.G
BT_EN.SIP: IC1.K17 (MII1_TXD0), R135.1
BT_HCI_CTS: IC11.8 (A7), R141.2
BT_HCI_CTS.SIP: IC1.M17 (MDIO_DATA), IC11.15 (B5), R108.1
BT_HCI_RTS: IC11.6 (A5), R140.2
BT_HCI_RTS.SIP: IC1.M18 (MDIO_CLK), IC11.13 (B7), R109.1
BT_HCI_RX: IC11.1 (A1), R143.2
BT_HCI_RX.SIP: IC1.L17 (MII1_RXD3), IC11.14 (B6)
BT_HCI_TX: IC11.7 (A6), R142.2
BT_HCI_TX.SIP: IC1.L16 (MII1_RXD2), IC11.20 (B1)
CEC: D1.C (CATHODE), IC9.30 (CEC), X5.15 (CEC)
CGND: MGT1.P$1, MGT2.P$1, MGT3.P$1, MGT4.P$1, R17.2, X2.CGND1, X2.CGND2, X2.CGND3, X2.CGND4, X2.CGND5, X2.CGND6, X3.5 (CG1), X3.6 (CG2), X4.CGND1 (SGND1), X4.CGND2 (SGND2), X4.CGND3 (SGND3), X4.CGND4 (SGND4), X4.CGND5 (SGND5), X4.CGND6 (SGND6), X5.CG1, X5.CG2, X5.CG3, X5.CG4
CLKOUT2: FB7.1, IC11.16 (B4), P2.18 (EMU3), P9.41, R14.1
DVI_5V: F1.1, R115.1, R118.1, X5.19 (5V)
EHRPWM1A: IC1.U14 (EHRPWM1A), P9.14
EHRPWM1B: IC1.T14 (EHRPWM1B), P9.16
EHRPWM2A: IC1.U10 (EHRPWM2A), P8.19
EHRPWM2B: IC1.T10 (EHRPWM2B), P8.13
EMMC_RSTN: IC22.K5 (RST#), R29.1, R33.1
EXT_SWING: IC9.34 (EXT_SWING), R119.1
GND: ANT1.GND1, ANT1.GND2, ANT2.GND1, ANT2.GND2, C1.2, C2.2, C7.2, C8.2, C9.2, C10.2, C11.-, C12.2, C13.2, C14.2, C15.2, C16.2, C17.2, C18.2, C19.2, C20.2, C21.2, C22.2, C23.-, C24.2, C25.2, C27.2, C28.2, C29.2, C30.2, C31.2, C32.2, C33.2, C34.2, C35.2, C36.2, C37.2, C38.2, C39.2, C40.2, C41.2, C42.2, C43.2, C44.2, C45.2, C47.2, C48.2, C49.2, C50.2, C51.2, C52.2, C53.2, C54.2, C55.2, C56.2, C57.2, C58.2, C59.2, C61.2, C62.-, C63.2, C64.2, C69.2, D8.2 (A2), IC1.A1 (DGND1), IC1.A18 (DGND2), IC1.E19 (DGND3), IC1.E20 (DGND4), IC1.F8 (DGND5), IC1.F19 (DGND6), IC1.G8 (DGND7), IC1.G9 (DGND8), IC1.G11 (DGND9), IC1.G12 (DGND10), IC1.G19 (DGND11), IC1.H6 (DGND12), IC1.H7 (DGND13), IC1.H8 (DGND14), IC1.H9 (DGND15), IC1.H10 (DGND16), IC1.H12 (DGND17), IC1.H19 (DGND18), IC1.J6 (DGND19), IC1.J7 (DGND20), IC1.J8 (DGND21), IC1.J9 (DGND22), IC1.J10 (DGND23), IC1.J11 (DGND24), IC1.J19 (DGND25), IC1.J20 (DGND26), IC1.K7 (DGND27), IC1.K9 (DGND28), IC1.K10 (DGND29), IC1.K11 (DGND30), IC1.K19 (DGND31), IC1.L10 (DGND32), IC1.L11 (DGND33), IC1.L12 (DGND34), IC1.L13 (DGND35), IC1.L19 (DGND36), IC1.M6 (DGND38), IC1.M7 (DGND39), IC1.M8 (DGND40), IC1.M9 (DGND41), IC1.M10 (DGND42), IC1.M12 (DGND43), IC1.M14 (DGND44), IC1.M19 (DGND45), IC1.N7 (DGND46), IC1.N10 (DGND47), IC1.N11 (DGND48), IC1.N14 (DGND49), IC1.N19 (DGND50), IC1.N20 (DGND51), IC1.P19 (DGND52), IC1.P20 (DGND53), IC1.R19 (DGND54), IC1.R20 (DGND55), IC1.T19 (DGND56), IC1.T20 (DGND57), IC1.U19 (DGND58), IC1.V1 (DGND59), IC1.V18 (DGND60), IC1.V19 (DGND61), IC1.W2 (DGND62), IC1.W3 (DGND63), IC1.W5 (DGND65), IC1.W6 (DGND66), IC1.W7 (DGND67), IC1.W8 (DGND68), IC1.W9 (DGND69), IC1.W10 (DGND70), IC1.W11 (DGND71), IC1.W12 (DGND72), IC1.W13 (DGND73), IC1.W14 (DGND74), IC1.W15 (DGND75), IC1.W16 (DGND76), IC1.W17 (DGND77), IC1.W18 (DGND78), IC1.W19 (DGND79), IC1.W20 (DGND80), IC1.Y7 (DGND82), IC1.Y10 (DGND83), IC1.Y12 (DGND84), IC1.Y15 (DGND85), IC1.Y18 (DGND86), IC2.3 (GND), IC3.3 (GND), IC4.2 (VSS), IC7.3 (GND1), IC7.8 (GND2), IC8.3 (GND1), IC8.8 (GND2), IC9.8 (VPB[1]), IC9.9 (VPB[0]), IC9.16 (VPC[2]), IC9.17 (VPC[1]), IC9.18 (VPC[0]), IC9.19 (VPP), IC9.53 (A0_I2C), IC9.54 (A1_I2C), IC9.61 (VPA[2]), IC9.62 (VPA[1]), IC9.63 (VPA[0]), IC9.65 (GND.PAD), IC10.11 (GND), IC10.TP, IC11.11 (GND), IC11.TP, IC12.1 (GND), IC12.9 (THERMAL), IC13.4 (GND), IC14.4 (GND), IC15.4 (GND), IC17.1 (1OE#), IC17.4 (GND), IC18.3 (GND1), IC18.6 (GND2), IC19.2 (GND), IC22.C4 (VSSQ1), IC22.E7 (VSS1), IC22.G5 (VSS2), IC22.H10 (VSS3), IC22.K8 (VSS4), IC22.N2 (VSSQ2), IC22.N5 (VSSQ3), IC22.P4 (VSSQ4), IC22.P6 (VSSQ5), MOD1.1 (GND1), MOD1.7 (GND2), MOD1.9 (GND3), MOD1.15 (GND4), MOD1.16 (GND5), MOD1.17 (GND6), MOD1.19 (GND7), MOD1.20 (GND8), MOD1.23 (GND9), MOD1.24 (GND10), MOD1.28 (GND11), MOD1.29 (GND12), MOD1.30 (GND13), MOD1.31 (GND14), MOD1.33 (GND15), MOD1.34 (GND16), MOD1.35 (GND17), MOD1.37 (GND18), MOD1.39 (GND19), MOD1.44 (GND20), MOD1.45 (GND21), MOD1.48 (GND22), MOD1.49 (GND23), MOD1.54 (GND24), MOD1.55 (GND25), MOD1.59 (GND26), MOD1.61 (GND27), MOD1.63 (GND28), MOD1.64 (GND29), MOD1.G1, MOD1.G2, MOD1.G3, MOD1.G4, MOD1.G5, MOD1.G6, MOD1.G7, MOD1.G8, MOD1.G9, MOD1.G10, MOD1.G11, MOD1.G12, MOD1.G13, MOD1.G14, MOD1.G15, MOD1.G16, MOD1.G17, MOD1.G18, MOD1.G19, MOD1.G20, MOD1.G21, MOD1.G22, MOD1.G23, MOD1.G24, MOD1.G25, MOD1.G26, MOD1.G27, MOD1.G28, MOD1.G29, MOD1.G30, MOD1.G31, MOD1.G32, MOD1.G33, MOD1.G34, MOD1.G35, MOD1.G36, OSC1.2 (GND), OSC2.2 (GND), P2.4 (TDIS), P2.8 (GND1), P2.10 (GND2), P2.12 (GND3), P2.16 (GND4), P2.20 (GND5), P8.1, P8.2, P9.1, P9.2, P9.43, P9.44, P9.45, P9.46, POWER.1, POWER.2, R10.2, R11.2, R17.1, R19.2, R22.2, R24.1, R27.2, R52.2, R55.1, R57.1, R61.1, R63.1, R65.1, R67.1, R69.1, R71.1, R73.1, R75.1, R85.1, R87.1, R94.2, R95.2, R106.2, R108.2, R109.2, R114.1, R119.2, R123.2, RESET.1, RESET.2, S2.3, S2.4, T3.S, T4.S, TP5.P$1, USR0.K, USR1.K, USR2.K, USR3.K, X1.1, X2.6 (VSS), X2.GND, X3.4 (GND), X4.GND, X5.4 (TMDS.DATA2.SHIELD), X5.7 (TMDS.DATA1.SHIELD), X5.10 (TMDS.DATA0.SHIELD), X5.13 (TMDS.CLOCK.SHIELD), X5.16 (DDC/CEC.GND), X12.OUT
GPIO0_7: P9.42, R36.1, R38.1
GPIO0_26: IC1.T11 (GPIO0_26), P8.14
GPIO0_27: IC1.U12 (GPIO0_27), P8.17
GPIO1_12: IC1.T12 (GPIO1_12), P8.12
GPIO1_13: IC1.R12 (GPIO1_13), P8.11
GPIO1_14: IC1.V13 (GPIO1_14), P8.16
GPIO1_15: IC1.U13 (GPIO1_15), P8.15
GPIO1_16: P9.15, R54.1
GPIO1_16.SIP: IC1.R13 (GPIO1_16), R54.2
GPIO1_17: IC1.V14 (GPIO1_17), P9.23
GPIO1_28: IC1.U18 (GPIO1_28), P9.12
GPIO1_29: IC1.V6 (GPIO1_29), P8.26
GPIO2_0.SIP: IC1.T13 (GPIO2_0)
GPIO2_1: IC1.V12 (GPIO2_1), P8.18
GPIO3_19: IC1.C13 (GPIO3_19), P9.27
GPIO3_21: IC1.A14 (GPIO3_21), P9.25, R110.2
HDMI.DSCL: IC9.33 (DSCL), R115.2, X5.17 (SCL)
HDMI.DSDA: IC9.32 (DSDA), R118.2, X5.18 (SDA)
HDMICLK_DIS#: IC1.V17 ((HDMICLK_DISN)GPIO1_27), OSC1.1 (INH#)
HDMI_1V8: C50.1, C51.1, C52.1, C53.1, C54.1, C55.1, C56.1, C57.1, FB2.2, IC9.5 (VDDDC1), IC9.14 (VDDD1(IO)(1V8)), IC9.29 (VDDDC2), IC9.35 (VDDA(1V8)), IC9.36 (VDDA1(TX)(1V8)), IC9.41 (VDDA2(TX)(1V8)), IC9.46 (VDDA3(TX)(1V8)), IC9.47 (VDDA1(PLL)(1V8)), IC9.48 (VDDA2(PLL)(1V8)), IC9.55 (VDDD2(IO)(1V8))
HDMI_INT: IC1.U16 ((HDMI_INT)GPIO1_25), IC9.50 (INT), R121.2
HPD: IC9.31 (HPD), X5.1 (HOT.PLUG.DETECT)
I2C0_SCL: IC1.C16 (I2C0_SCL), IC1.C20 (PMIC_I2C_SCL), IC4.1 (SCL), IC9.52 (CSCL), R41.2
I2C0_SDA: IC1.C17 (I2C0_SDA), IC1.C19 (PMIC_I2C_SDA), IC4.3 (SDA), IC9.51 (CSDA), R42.2
I2C1_SCL: IC1.A16 (I2C1_SCL), P9.17
I2C1_SDA: IC1.B16 (I2C1_SDA), P9.18
I2C2_SCL: IC1.D17 (I2C2_SCL), P9.19
I2C2_SDA: IC1.D18 (I2C2_SDA), P9.20
JTAG_EMU0: IC1.C14 (JTAG_EMU0), P2.13 (EMU0), R43.2
JTAG_EMU1: IC1.B14 (JTAG_EMU1), P2.14 (EMU1), R53.2
JTAG_TCK: IC1.A12 (JTAG_TCK), P2.9 (TCKRTN), P2.11 (TCK)
JTAG_TDI: IC1.B11 (JTAG_TDI), P2.3 (TDI)
JTAG_TDO: IC1.A11 (JTAG_TDO), P2.7 (TDO)
JTAG_TMS: IC1.C11 (JTAG_TMS), P2.1 (TMS)
JTAG_TRSTN: IC1.B10 (JTAG_TRSTN), P2.2 (TRST#), R52.1
LCD.CLOCK: IC9.4 (PCLK), P8.28, R34.1
LCD.D0.B0--B3: C42.1, IC1.R1 (LCD_DATA0), IC9.15 (VPC[3]), P8.45, R87.2
LCD.D1.B1--B4: C41.1, IC1.R2 (LCD_DATA1), IC9.13 (VPC[4]), P8.46, R85.2
LCD.D2.B2--B5: C40.1, IC1.R3 (LCD_DATA2), IC9.12 (VPC[5]), P8.43, R82.1, R88.1
LCD.D3.B3--B6: C39.1, IC1.R4 (LCD_DATA3), IC9.11 (VPC[6]), P8.44, R80.1
LCD.D4.B4--B7: C38.1, IC1.T1 (LCD_DATA4), IC9.10 (VPC[7]), P8.41, R78.1
LCD.D5.G0--G2: C37.1, IC1.T2 (LCD_DATA5), IC9.7 (VPB[2]), P8.42, R76.1
LCD.D6.G1--G3: C36.1, IC1.T3 (LCD_DATA6), IC9.6 (VPB[3]), P8.39, R75.2
LCD.D7.G2--G4: C35.1, IC1.T4 (LCD_DATA7), IC9.3 (VPB[4]), P8.40, R73.2
LCD.D8.G3--G5: C34.1, IC1.U1 (LCD_DATA8), IC9.2 (VPB[5]), P8.37, R71.2
LCD.D9.G4--G6: C33.1, IC1.U2 (LCD_DATA9), IC9.1 (VPB[6]), P8.38, R69.2
LCD.D10.G5--G7: C32.1, IC1.U3 (LCD_DATA10), IC9.64 (VPB[7]), P8.36, R67.2
LCD.D11.R0--R3: C31.1, IC1.U4 (LCD_DATA11), IC9.60 (VPA[3]), P8.34, R65.2
LCD.D12.R1--R4: C30.1, IC1.V2 (LCD_DATA12), IC9.59 (VPA[4]), P8.35, R63.2
LCD.D13.R2--R5: C29.1, IC1.V3 (LCD_DATA13), IC9.58 (VPA[5]), P8.33, R61.2
LCD.D14.R3--R6: C28.1, IC1.V4 (LCD_DATA14), IC9.57 (VPA[6]), P8.31, R58.1
LCD.D15.R4--R7: C27.1, IC1.T5 (LCD_DATA15), IC9.56 (VPA[7]), P8.32, R57.2
LCD.ENABLE: IC9.20 (DE/FREF), P8.30, R39.1
LCD.HSYNC: IC9.22 (HSYNC/HREF), P8.29, R37.1
LCD.VSYNC: IC9.21 (VSYNC/VREF), P8.27, R35.1
LDO_PGOOD: IC1.B5 (RTC_PORZ), IC1.B20 (PMIC_LDO_PGOOD)
LS_BUF_OE: IC1.L18 (MII_RXCLK), R131.2
MCU.LCD.CLK: IC1.V5 (LCD_PCLK), R34.2
MCU.LCD.EN: IC1.R6 (LCD_DE), R39.2
MCU.LCD.HS: IC1.R5 (LCD_HSYNC), R37.2
MCU.LCD.VS: IC1.U5 (LCD_VSYNC), R35.2
MMC1_CLK: IC1.U9 (MMC1_CLK), IC22.M6 (CLK), P8.21, R31.1
MMC1_CMD: IC1.V9 (MMC1_CMD), IC22.M5 (CMD), P8.20, R30.1
MMC1_DAT0: IC1.U7 (MMC1_DAT0), IC22.A3 (DAT0), P8.25, R12.1
MMC1_DAT1: IC1.V7 (MMC1_DAT1), IC22.A4 (DAT1), P8.24, R13.1
MMC1_DAT2: IC1.R8 (MMC1_DAT2), IC22.A5 (DAT2), P8.5, R16.1
MMC1_DAT3: IC1.T8 (MMC1_DAT3), IC22.B2 (DAT3), P8.6, R18.1
MMC1_DAT4: IC1.U8 (MMC1_DAT4), IC22.B3 (DAT4), P8.23, R20.1
MMC1_DAT5: IC1.V8 (MMC1_DAT5), IC22.B4 (DAT5), P8.22, R23.1
MMC1_DAT6: IC1.R9 (MMC1_DAT6), IC22.B5 (DAT6), P8.3, R25.1
MMC1_DAT7: IC1.T9 (MMC1_DAT7), IC22.B6 (DAT7), P8.4, R28.1
unnamed: OSC2.1 (EN), R90.2
unnamed: R88.2, S2.1, S2.2
unnamed: FB5.1, IC1.A15 (CLKOUT1)
unnamed: PWR.K, R55.2
unnamed: IC18.1 (SHDN#), R89.2, R97.2
unnamed: C4.1, IC1.K20 (OSC0_OUT), Q4.1, R8.1
unnamed: C3.1, IC1.M20 (OSC0_IN), Q4.2, R8.2
unnamed: IC1.C6 (PMIC_POWER_EN), IC1.D19 (PWR_EN)
unnamed: IC18.5 (ADJ), R93.2, R94.1
unnamed: C3.2, C4.2, IC1.L20 (DGND0)
unnamed: C5.2, C6.2, IC1.G20 (DGND1)
unnamed: ANT2.SIG, C60.1
unnamed: ANT1.SIG, C46.1
unnamed: C46.2, MOD1.32 (RF_ANT1)
unnamed: R100.1, USR1.A
unnamed: R96.1, USR2.A
unnamed: R92.1, USR3.A
unnamed: C60.2, MOD1.18 (RF_ANT2)
unnamed: IC1.P17 (USB1_ID), R27.1
unnamed: IC1.B4 (RTC_KALDO_ENN), R24.2
unnamed: T3.D, WL.K
unnamed: IC1.D13 (GPIO3_20), R14.2
unnamed: FB7.2, IC1.D14 (CLKOUT2)
unnamed: IC1.R14 ((EMMC_RSTN)GPIO1_20), IC3.2 (A)
unnamed: IC3.4 (Y), R29.2
unnamed: MOD1.26 (GPIO2), TP12.TP
unnamed: R104.1, USR0.A
unnamed: MOD1.27 (GPIO1), TP13.TP
unnamed: C5.1, IC1.H20 (OSC1_IN), Q2.P$1, R56.2
unnamed: C6.1, IC1.F20 (OSC1_OUT), Q2.P$2, R56.1
unnamed: MOD1.42 (WL_UART_DBG), TP14.TP
unnamed: MOD1.43 (BT_UART_DBG), TP15.TP
unnamed: MOD1.56 (BT_AUD_IN), TP16.TP
unnamed: MOD1.57 (BT_AUD_OUT), TP17.TP
unnamed: OSC1.3 (OUT), R110.1
unnamed: MOD1.58 (BT_AUD_FSYNC), TP18.TP
unnamed: MOD1.60 (BT_AUD_CLK), TP19.TP
unnamed: IC1.P15 (USB0_VBUS), R26.1
unnamed: C7.1, C69.1, IC22.C2 (VDDI)
unnamed: IC1.C18 (GPIO0_7), R36.2
unnamed: IC1.B12 (GPIO3_18), R38.2
unnamed: IC5.2 (C), R44.2, R45.1, T1.B
unnamed: IC5.1 (FB), R45.2, R46.2, R47.1
unnamed: IC6.2 (C), R48.2, R49.1, T2.B
unnamed: IC6.1 (FB), R49.2, R50.2, R51.1
unnamed: IC4.5 (WP), R40.2, TP1.P$1
unnamed: BT.K, T4.D
unnamed: R125.1, WL.A
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

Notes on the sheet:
<-- SYS_BOOT0 <-- SYS_BOOT1 <-- SYS_BOOT2 <-- SYS_BOOT3 <-- SYS_BOOT4 <-- SYS_BOOT5 <-- SYS_BOOT6 <-- SYS_BOOT7 <-- SYS_BOOT8 <-- SYS_BOOT9 <-- SYS_BOOT10 <-- SYS_BOOT11 <-- SYS_BOOT12 <-- SYS_BOOT13 <-- SYS_BOOT14 <-- SYS_BOOT15
uSD BOOT
Power
RESET#
USB Device
USB Host
EEPROM
HDMI Interface
BeagleBone Black Configuration
BeagleBone Black Headers
USER LEDs
eMMC 4GB
JTAG
Did not include the transistor array
Used a tantalum cap instead of the large aluminum cap
We are using fuse instead of the PCE power Trip
uSD Connector
SEE NOTES IN GREEN
WiFi Module
1.8V WiFi Power Regulator
OSD3358 SiP
Prototyped by: GHI Electronics, LLC
GHI-PROTO-BBBW-REV-A5

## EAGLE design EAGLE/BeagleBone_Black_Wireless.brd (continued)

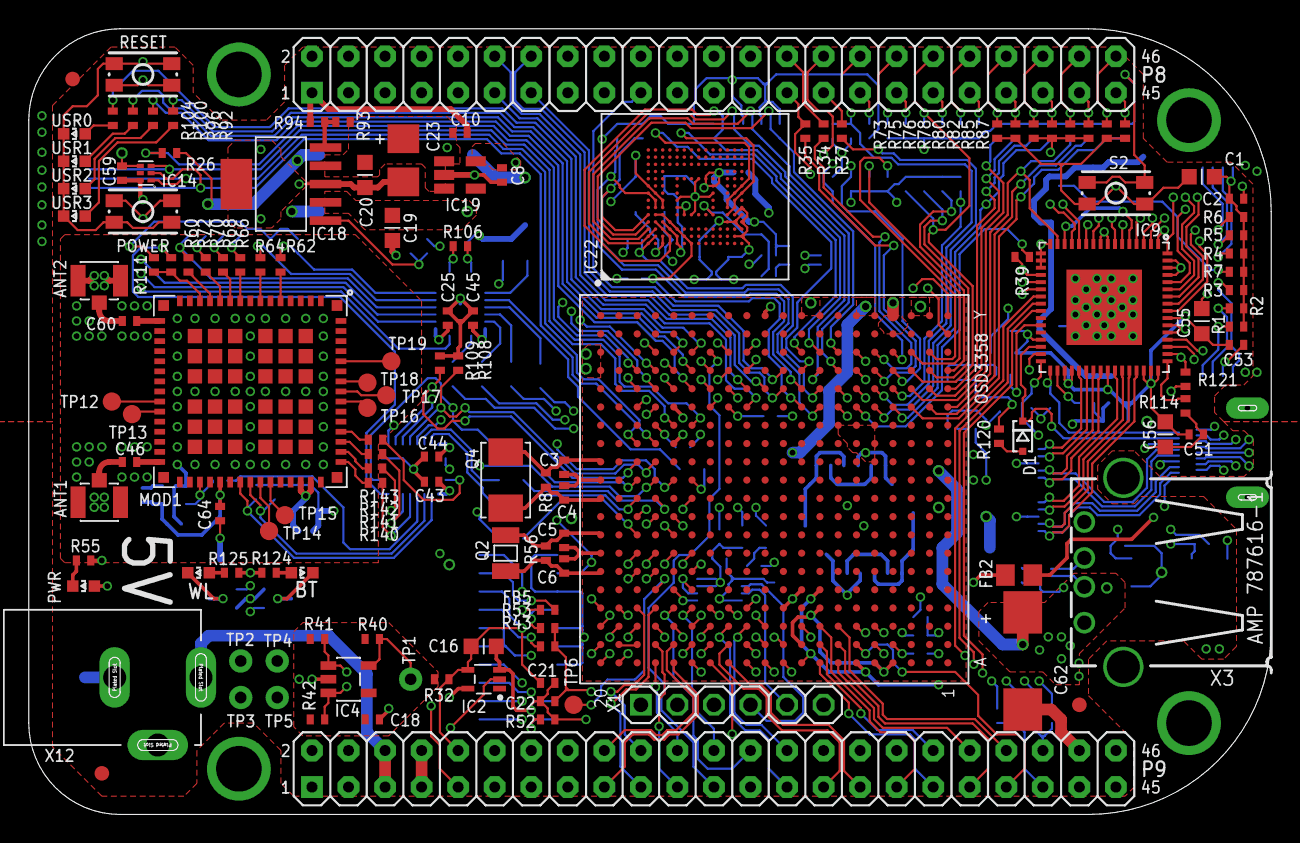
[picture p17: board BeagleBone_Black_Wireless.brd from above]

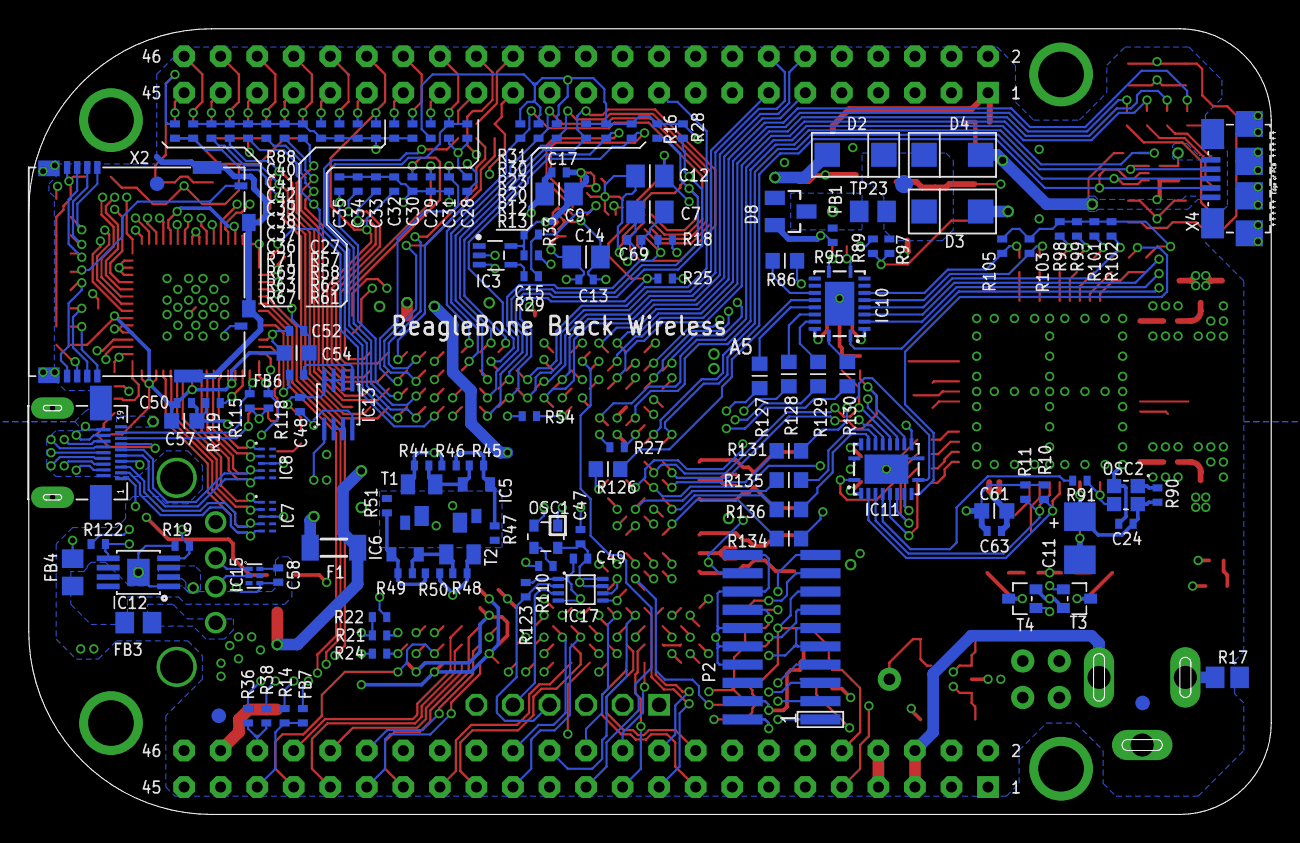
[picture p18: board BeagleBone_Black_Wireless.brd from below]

Board: 6 copper layers, 86.4 x 54.6 mm, 275 parts (139 on the bottom side), 262 nets.

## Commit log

2016-08-23 Initial A3 files
    [BeagleBone_Black_Wireless.brd, BeagleBone_Black_Wireless.sch]
2016-08-23 Rename schematic PDF
2016-09-27 Add BOM
    [BeagleBone_Black_Wireless_BOM.xls]
2016-09-28 Add rev A5 source files
    [BeagleBone_Black_Wireless.brd, BeagleBone_Black_Wireless.sch]
2016-09-28 Move source files to EAGLE folder for clarity
    [BeagleBone_Black_Wireless.brd, BeagleBone_Black_Wireless.sch]
2016-10-28 PCB rev A5b: Added vias to pads
    This is meant to assist in avoiding pads coming off with excess pressure.
    [BeagleBone_Black_Wireless.brd, BeagleBone_Black_Wireless.sch]
2016-10-29 Update BOM
    [BeagleBone_Black_Wireless_BOM.csv, BeagleBone_Black_Wireless_BOM.xls]
2016-11-15 Added PDF of PCB
2016-11-22 BOM: add alternate based on lead times
    [BeagleBone_Black_Wireless_BOM.csv]
2017-01-20 BOM: fix missing R68
    [BeagleBone_Black_Wireless_BOM.csv]
